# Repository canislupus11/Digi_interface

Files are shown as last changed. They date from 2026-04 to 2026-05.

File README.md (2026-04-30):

<div align="center">
<br>


</div>

# Uniwersalny Interfejs Radiowy / Universal Radio Interface

> Kraków, 31 sierpnia 2026 | Hackerspace Kraków  
> Licencja / License: [CC BY-NC-SA](https://creativecommons.org/licenses/by-nc-sa/4.0/)

---

##  Polski (English below)

### Opis projektu

Uniwersalny interfejs radiowy to otwarto-sprzętowy projekt płytki PCB, której celem jest stworzenie jak najbardziej elastycznego interfejsu do **emisji cyfrowych** oraz **zdalnej kontroli urządzeń radiowych (TRX)**. Interfejs zaprojektowano z myślą o kompatybilności z możliwie największą liczbą modeli i producentów transceiverów.

### Główne założenia

- **Uniwersalność** – współpraca z szeroką gamą modeli TRX różnych producentów
- **Minimalizacja okablowania** – w skrajnym przypadku wystarczy kabel USB i kabel sygnałowy do radia
- **Pełna separacja galwaniczna** – izolacja zaraz za gniazdem USB chroni sprzęt przed przepięciami i biegającym RF

### Moduły

| # | Moduł | Chip |
|---|---|---|
| 1 | HUB USB | **Fe1.1s** |
| 2 | Kodek dźwięku na USB (źródło dla emisji cyfrowych) | **CM108B** |
| 3 | 4-portowy konwerter USB → UART (CAT/CI-V, CW, PTT, FSK) | **CP2105** |
| 4 | Konwerter poziomów RS232/TTL | **MAX232** |
| 5 | Zasilacz (szeroki zakres napięć wejściowych: 7–18 V) | **AMS1117-5.0** |
| 6 | Moduł zworkologii – konfiguracja portów CAT, linii CW, PTT i FSK (w tym z konwerterem poziomów) | – |

### PCB

- Dwustronna płytka w technologii SMD
- Projekt wykonany w **KiCad 9** — pliki schematu, PCB oraz biblioteki footprintów i symboli dostępne w tym repozytorium
- Elementy mają przypisane identyfikatory JLCPCB, dzięki czemu można bezpośrednio zamówić płytkę z usługą montażu SMD (PCBA) — wystarczy wygenerować pliki Gerber, BOM i pliki pick & place z KiCad i wgrać je na stronę JLCPCB
- Katalog `bom/` zawiera interaktywny plik HTNL ułatwiający montaż

### Jak zacząć

1. Sklonuj lub pobierz repozytorium
2. Otwórz `interfejs_digi.kicad_pro` w KiCad 9
3. Przejrzyj schemat (`interfejs_digi.kicad_sch`) i projekt PCB (`interfejs_digi.kicad_pcb`)
4. Wygeneruj pliki Gerber, BOM oraz pick & place z poziomu KiCad
5. Wgraj pliki na stronę [JLCPCB](https://jlcpcb.com) i zamów płytkę z montażem SMD (PCBA) — identyfikatory elementów są już uzupełnione
6. Po otrzymaniu płytki skonfiguruj zworki zgodnie z używanym modelem TRX

### Pinout gniazd RJ45

Interfejs wyprowadza sygnały na dwóch gniazdach RJ45 (HX-RJ45 90 5631-1X1 8P8C).

**RJ1 — gniazdo główne**

| Pin | Sygnał | Opis |
|-----|---|---|
| 1 | CAT1\_RX | CAT RX/CI-V (port 1) |
| 2 | CAT1\_TX | CAT TX (port 1) |
| 3 | GND\_IN | Masa zasilania |
| 4 | PWR\_IN | Zasilanie 7-18V (wejście) |
| 5 | PTT\_OUT | Wyjście PTT (otwarty dren, tranzystor 2N7002) |
| 6 | GND | Masa sygnałowa |
| 7 | AUDIO\_OUT | Wyjście audio do radia (TX) |
| 8 | AUDIO\_IN | Wejście audio z radia (RX) |

**RJ2 — gniazdo dodatkowe**

| Pin | Sygnał | Opis |
|-----|---|---|
| 1 | CAT2\_RX | CAT RX (port 2) |
| 2 | CAT2\_TX | CAT TX (port 2) |
| 3 | FSK\_OUT | Wyjście FSK (otwarty dren, tranzystor 2N7002) |
| 4 | 5V_OUT | Wyjście 5V za stabilizatorem |
| 5 | CW\_OUT | Wyjście kluczowania CW (otwarty dren, tranzystor 2N7002) |
| 6 | – | Niepodłączony |
| 7 | – | Niepodłączony |
| 8 | – | Niepodłączony |

Wyjścia PTT, CW i FSK są wyjściami otwartego drenu przez tranzystor MOSFET 2N7002 z diodą LED sygnalizacyjną. Masa obu gniazd jest wspólna (pin 10 złącza RJ45 podłączony do GND).

### Konfiguracja zworkami

Zworki J7–J11 pozwalają elastycznie przypisać sygnały do linii sterujących oraz wybrać poziomy napięć. Każda zworka ma 6 pinów (3 pary), co umożliwia niezależny wybór dla każdej linii.

**J7, J8 — CAT\_1 i CAT\_2**

Pod każdym złączem CAT znajduje się goldpin 2×3 z dwiema klasycznymi zworkami — osobno dla linii RX i TX. Obie zworki ustawia się zawsze w tej samej pozycji. Konfiguracja jest wspólna dla CAT\_1 i CAT\_2:

| Pozycja zworek | Poziom sygnału |
|---|---|
| obie zworki **w górze** | TTL (5 V) |
| obie zworki **w dole** | RS232 (±12 V) |

**J9 — CW** — wybór źródła sygnału CW spośród linii UART:

| Pozycja zworki | Źródło |
|---|---|
| piny 1–2 | DTR\_1 |
| piny 3–4 | RTS\_1 |
| piny 5–6 | RTS\_2 |

**J10 — PTT** — wybór źródła sygnału PTT:

| Pozycja zworki | Źródło |
|---|---|
| piny 1–2 | DTR\_1 |
| piny 3–4 | RTS\_1 |
| piny 5–6 | RTS\_2 |

**J11 — FSK** — wybór źródła sygnału FSK:

| Pozycja zworki | Źródło |
|---|---|
| piny 1–2 | DTR\_2 |
| piny 3–4 | RTS\_2 |
| piny 5–6 | RTS\_1 |

**J2 — CI-V** — gniazdo CI-V (Icom). Po włożeniu zworki sygnał CAT1\_TX\_TTL jest zwrotnie podłączony przez diodę D5 (1N5819WS) do CAT1\_RX\_TTL, realizując magistralę jednolinową wymaganą przez protokół CI-V.

**LDO\_BYPASS** — lutowana zworka (solder jumper) bypasująca stabilizator napięcia (AMS1117-5.0). Jeśli układ jest zasilany napięciem **5 V** zamiast standardowych 7–18 V (np. bezpośrednio z zasilacza 5 V przez gniazdo RJ1 pin 4), należy zewrzeć tę zworkę cyną, aby ominąć regulator LDO.

> **Ostrzeżenie:** Po zwarciu zworki LDO\_BYPASS stabilizator napięcia jest całkowicie pomijany. Napięcie zasilające trafia bezpośrednio na układ bez żadnej regulacji. Podanie napięcia wyższego niż 5 V przy zwartej zworce **może trwale uszkodzić układ**. Przed podaniem zasilania upewnij się, że źródło napięcia dostarcza dokładnie 5 V.

### Licencja

Projekt udostępniony na licencji **Creative Commons BY-NC-SA**. Możesz go swobodnie używać, modyfikować i udostępniać pod warunkiem podania autora, zachowania tej samej licencji i braku użytku komercyjnego.

---

##  English

### Project Description

The Universal Radio Interface is an open-hardware PCB project designed to provide a flexible interface for **digital mode operations** and **remote control of radio transceivers (TRX)**. The board is designed to be compatible with as many TRX models and manufacturers as possible.

### Design Goals

- **Universality** – works with a wide range of TRX models from various manufacturers
- **Minimal cabling** – in the simplest setup only a USB cable and radio signal cable needed
- **Full galvanic isolation** – isolation placed immediately after the USB connector protects equipment from voltage spikes and stray RF

### Modules

| # | Module | Chip |
|---|---|---|
| 1 | USB Hub | **Fe1.1s** |
| 2 | USB Audio Codec (source for digital modes) | **CM108B** |
| 3 | 4-port USB → UART converter (CAT/CI-V, CW, PTT, FSK) | **CP2105** |
| 4 | RS232/TTL Level Converter | **MAX232** |
| 5 | Power Supply (wide input voltage range: 7–18 V) | **AMS1117-5.0** |
| 6 | Jumper configuration module – configures CAT ports, CW, PTT and FSK lines (including level converter options) | – |

### PCB

- Double-sided SMD board
- Designed in **KiCad 9** — schematic, PCB layout, footprint and symbol libraries all included in this repository
- All components have JLCPCB part IDs assigned, so the board can be ordered with SMD assembly (PCBA) — simply generate Gerber, BOM and pick & place files from KiCad and upload them to JLCPCB
- The `bom/` directory contains an interactive HTML file to assist with assembly.

### Getting Started

1. Clone or download this repository
2. Open `interfejs_digi.kicad_pro` in KiCad 9
3. Review the schematic (`interfejs_digi.kicad_sch`) and PCB layout (`interfejs_digi.kicad_pcb`)
4. Generate Gerber, BOM and pick & place files from KiCad
5. Upload the files to [JLCPCB](https://jlcpcb.com) and order the board with SMD assembly (PCBA) — component IDs are already filled in
6. Once the board arrives, configure the jumpers for your TRX model

### RJ45 Connector Pinout

The interface exposes signals on two RJ45 connectors (HX-RJ45 90 5631-1X1 8P8C). 

**RJ1 — Main connector**

| Pin | Signal | Description |
|-----|---|---|
| 1 | CAT1\_RX | CAT/CI-V receive (port 1) |
| 2 | CAT1\_TX | CAT/CI-V transmit (port 1) |
| 3 | GND\_IN | Power ground |
| 4 | PWR\_IN | 7-18V power input |
| 5 | PTT\_OUT | PTT output (open drain, 2N7002 MOSFET) |
| 6 | GND | Signal ground |
| 7 | AUDIO\_OUT | Audio output to radio (TX) |
| 8 | AUDIO\_IN | Audio input from radio (RX) |

**RJ2 — Secondary connector**

| Pin | Signal | Description |
|-----|---|---|
| 1 | CAT2\_RX | CAT receive (port 2) |
| 2 | CAT2\_TX | CAT transmit (port 2) |
| 3 | FSK\_OUT | FSK output (open drain, 2N7002 MOSFET) |
| 4 | 5V_OUT | 5V output, after LDO |
| 5 | CW\_OUT | CW keying output (open drain, 2N7002 MOSFET) |
| 6 | – | Not connected |
| 7 | – | Not connected |
| 8 | – | Not connected |

PTT, CW and FSK outputs are open-drain via 2N7002 MOSFET transistors, each with a status LED indicator. The ground of both connectors is shared (RJ45 pin 10 tied to GND).

### Jumper Configuration

Jumpers J7–J11 allow flexible assignment of signals to control lines and voltage level selection. Each jumper has 6 pins (3 pairs), enabling independent selection per line.

**J7, J8 — CAT\_1 and CAT\_2**

Below each CAT connector there is a 2×3 pin header with two standard jumpers — one for RX and one for TX. Both jumpers are always set to the same position. The configuration applies equally to CAT\_1 and CAT\_2:

| Jumper position | Signal level |
|---|---|
| both jumpers **up** | TTL (5 V) |
| both jumpers **down** | RS232 (±12 V) |

**J9 — CW** — selects the UART line used as the CW source:

| Jumper position | Source |
|---|---|
| pins 1–2 | DTR\_1 |
| pins 3–4 | RTS\_1 |
| pins 5–6 | RTS\_2 |

**J10 — PTT** — selects the PTT source:

| Jumper position | Source |
|---|---|
| pins 1–2 | DTR\_1 |
| pins 3–4 | RTS\_1 |
| pins 5–6 | RTS\_2 |

**J11 — FSK** — selects the FSK source:

| Jumper position | Source |
|---|---|
| pins 1–2 | DTR\_2 |
| pins 3–4 | RTS\_2 |
| pins 5–6 | RTS\_1 |

**J2 — CI-V** — CI-V connector (Icom radios). When a jumper is inserted, CAT1\_TX\_TTL is looped back through diode D5 (1N5819WS) to CAT1\_RX\_TTL, implementing the single-wire bus required by the CI-V protocol.

**LDO\_BYPASS** — solder jumper that bypasses the voltage regulator (AMS1117-5.0). If the board is powered at **5 V** instead of the standard 7–18 V range (e.g. directly from a 5 V supply via RJ1 pin 4), bridge this solder jumper to bypass the LDO regulator.

> **Warning:** When the LDO\_BYPASS solder jumper is bridged, the voltage regulator is completely bypassed. The supply voltage is fed directly to the circuitry with no regulation. Applying more than 5 V with this jumper bridged **can permanently damage the board**. Always verify that your power source provides exactly 5 V before powering on.

### License

This project is released under the **Creative Commons BY-NC-SA** license. You are free to use, modify, and share it as long as you credit the author, keep the same license, and do not use it commercially.

---

*Design by Szymon Reiter / Hackerspace Kraków*

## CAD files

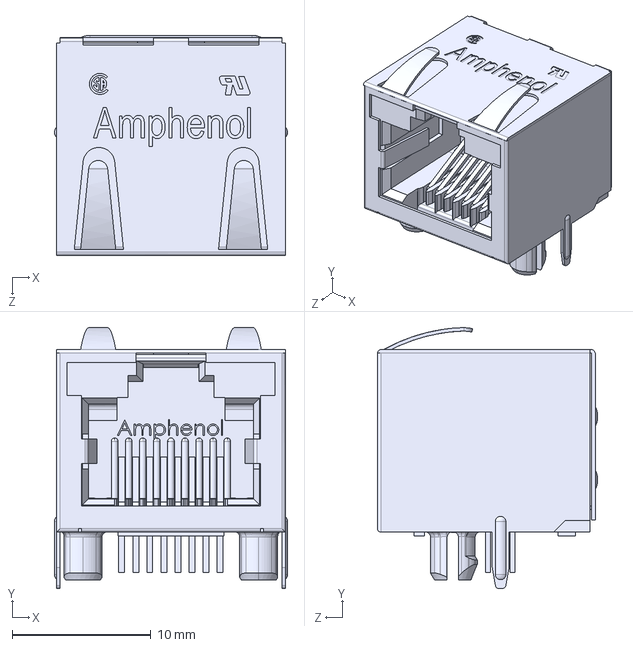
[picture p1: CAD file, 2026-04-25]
KiCad/3dshapes/RJHSE-538B--3DModel-STEP-56544.STEP
16.8 x 18.8 x 15.9 mm

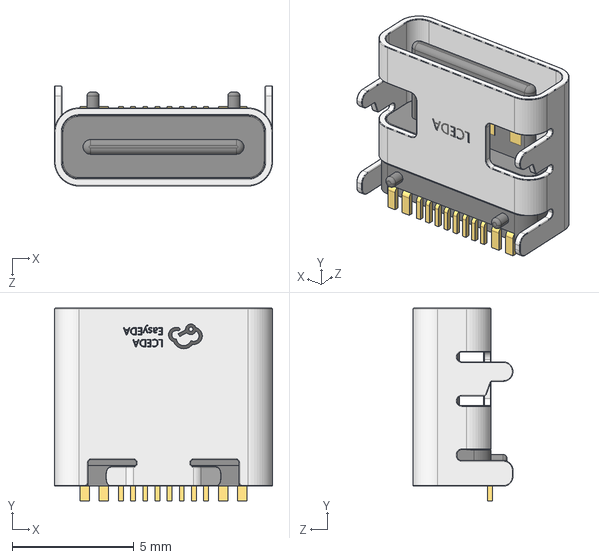
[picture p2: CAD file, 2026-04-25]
KiCad/3dshapes/USB-C-SMD_TYPE-C16PIN.step
8.94 x 7.90 x 4.10 mm

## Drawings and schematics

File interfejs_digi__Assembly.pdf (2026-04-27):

1 | 2 | 3 | 4

A

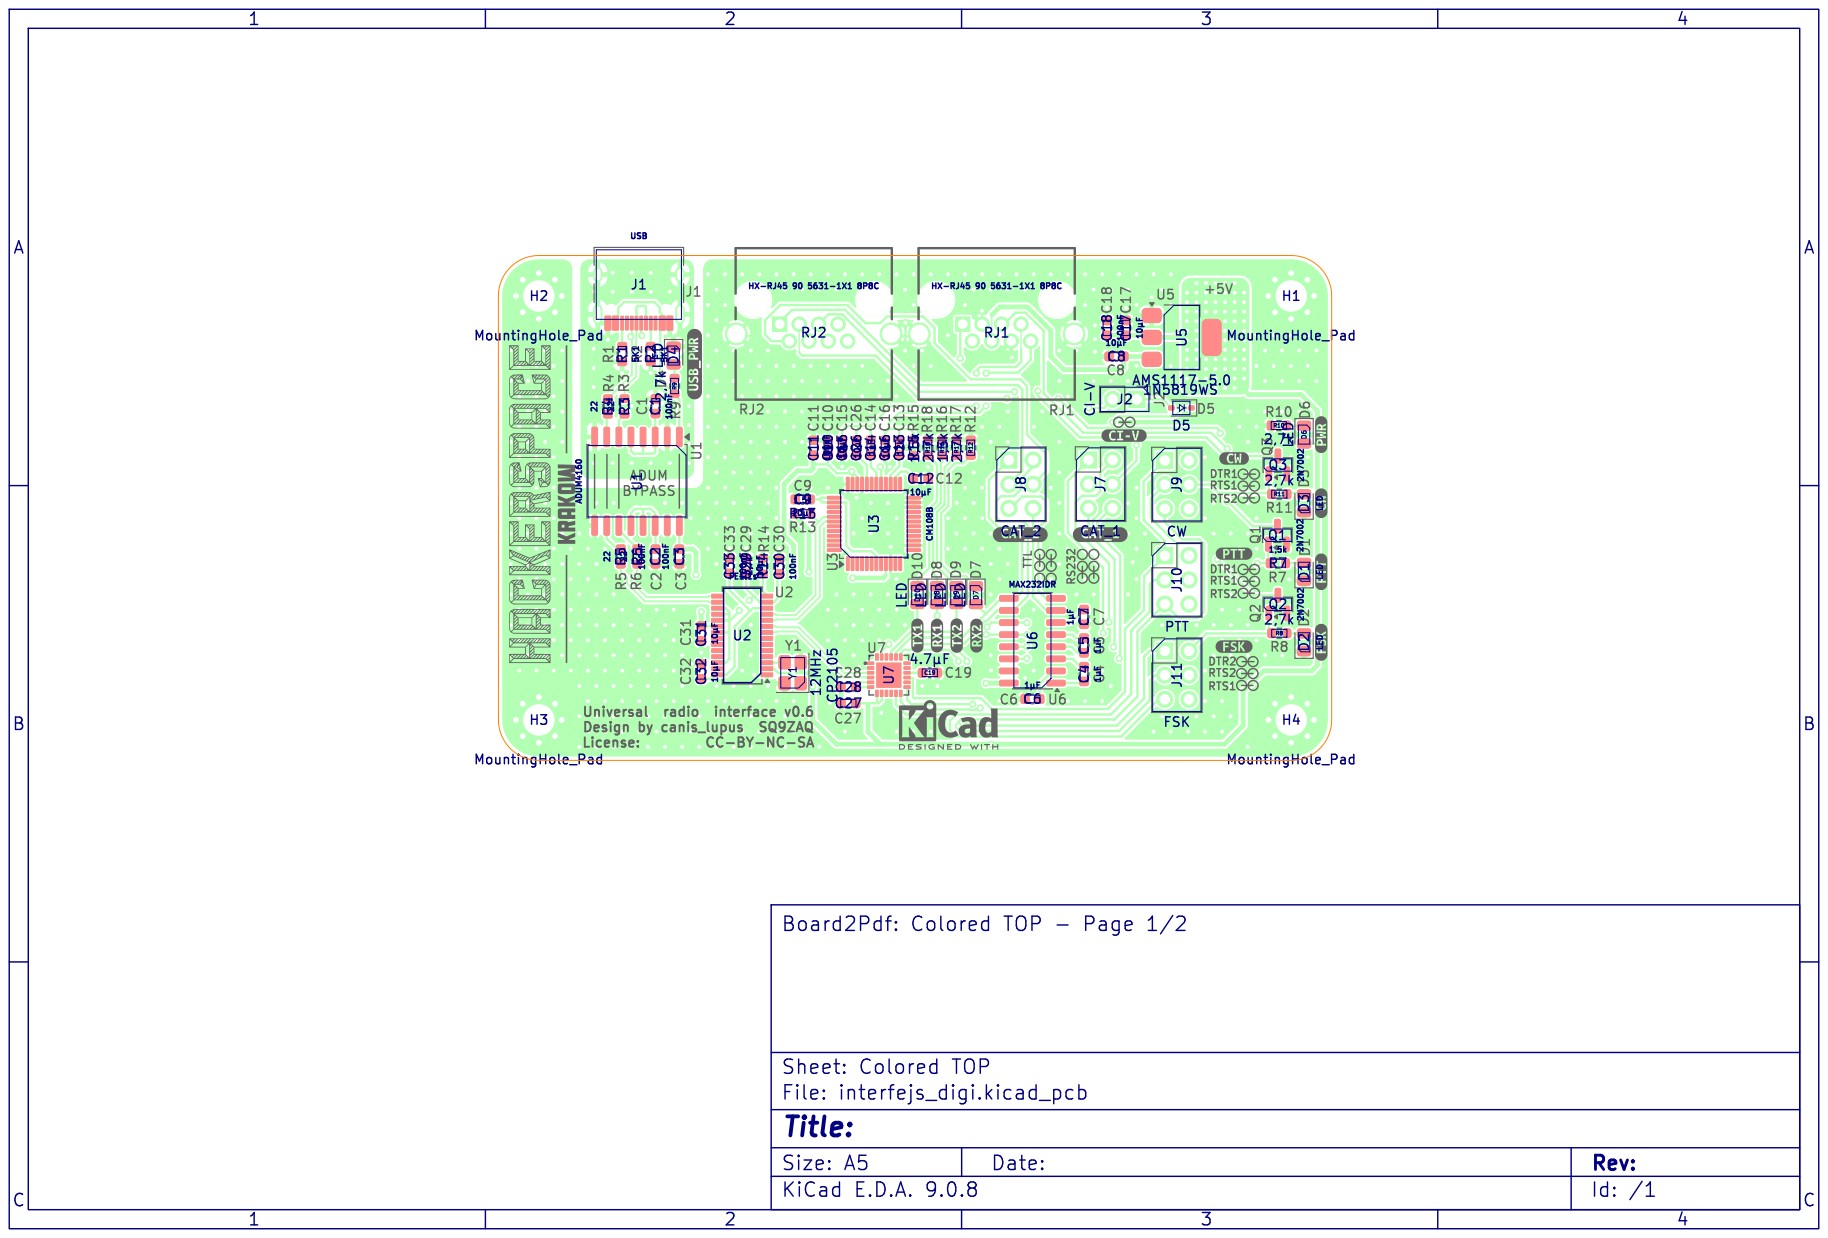
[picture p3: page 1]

Id: /1 Title: File: interfejs_digi.kicad_pcb Sheet: Colored TOP

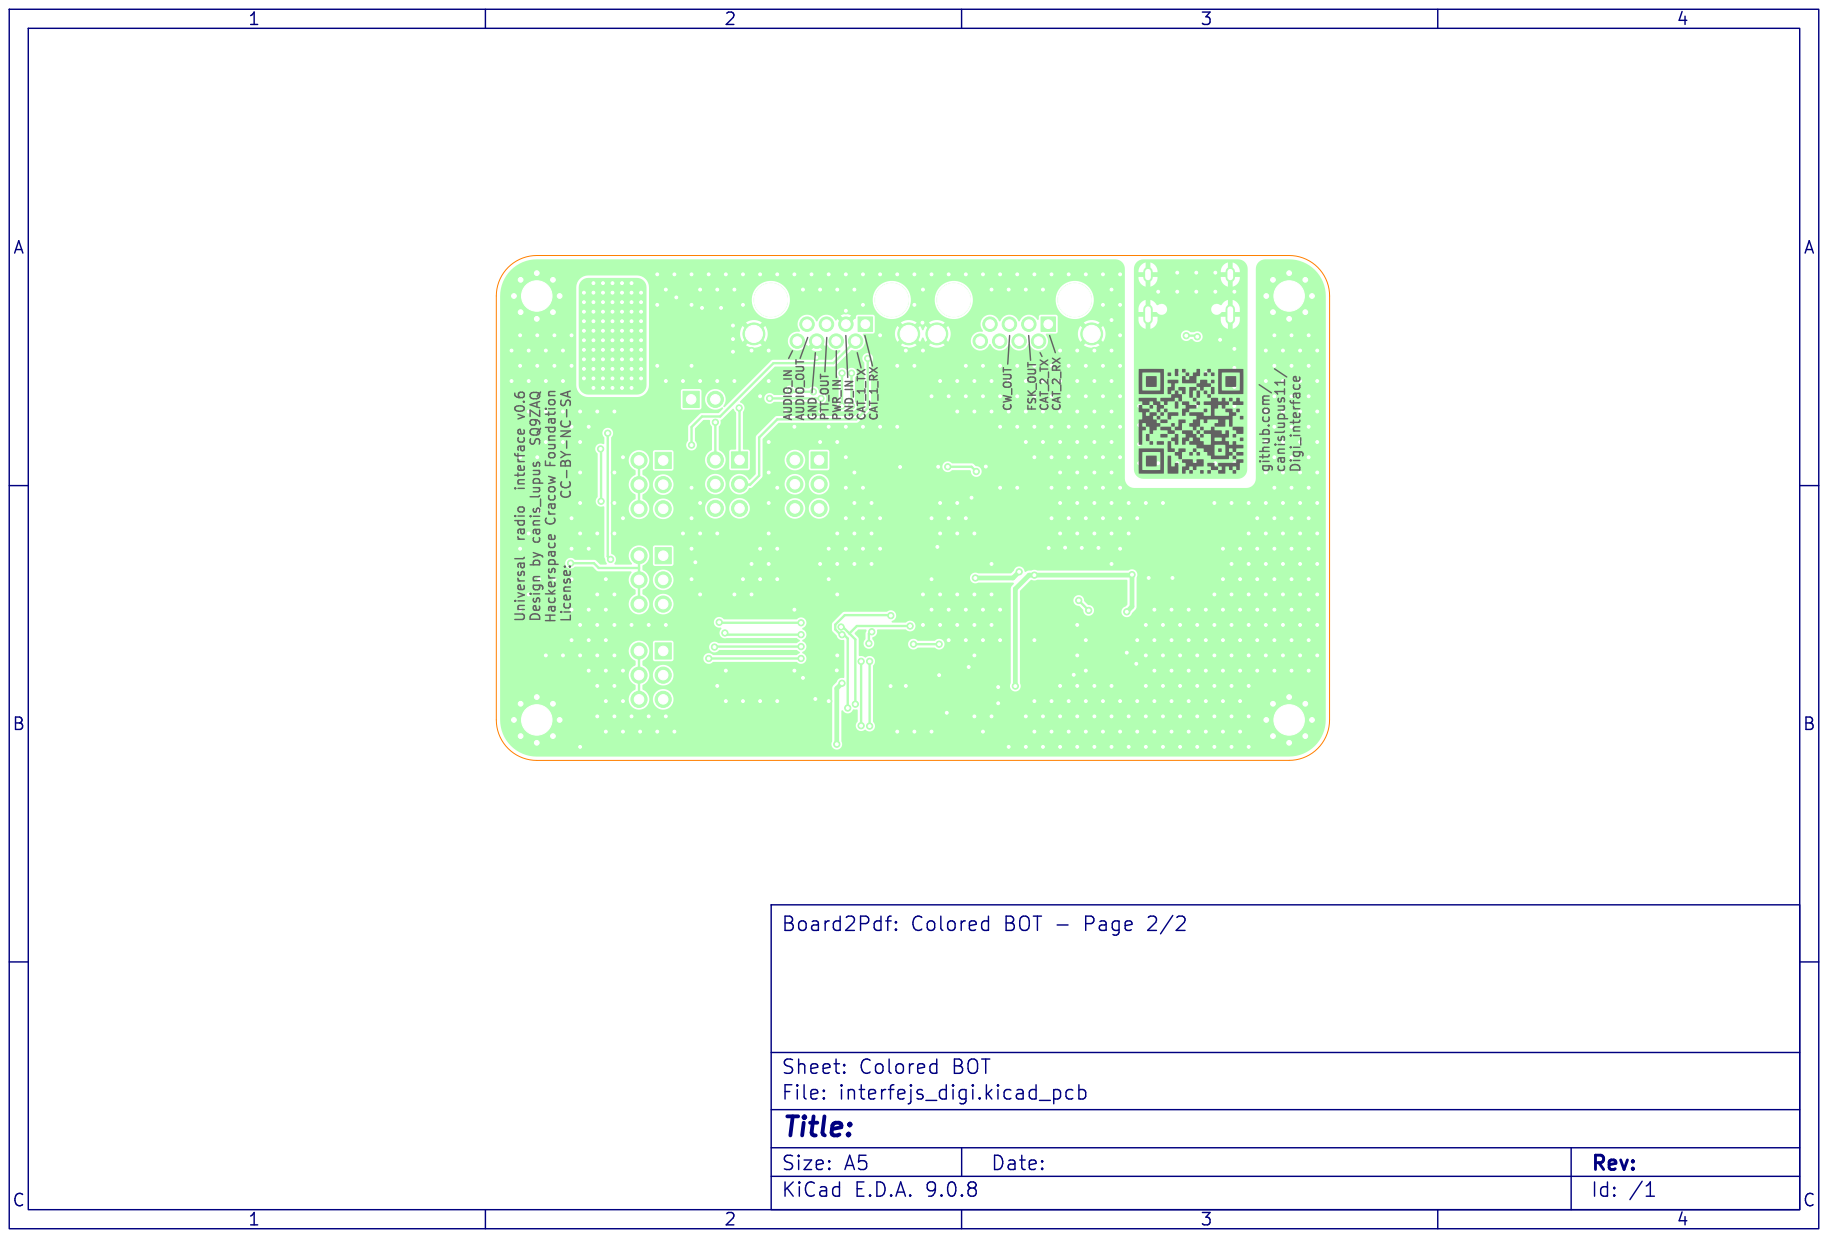
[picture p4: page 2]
Id: /1 Title: File: interfejs_digi.kicad_pcb Sheet: Colored; BOT Board2Pdf:; Colored; BOT -; Page 2/2

CW_OUT FSK_OUT CAT_2_TX CAT_2_RX AUDIO_IN AUDIO_OUT GND PTT_OUT PWR_IN GND_IN CAT_1_TX CAT_1_RX github.com/ canislupus11/ Digi_interface Universal radio interface v0.6 Design by canis_lupus SQ9ZAQ Hackerspace Cracow Foundation License: CC-BY-NC-SA 1 2 3 4 1 2 3 4 ABC ABC Date: KiCad E.D.A. 9.0.8 Size: A5 Rev:

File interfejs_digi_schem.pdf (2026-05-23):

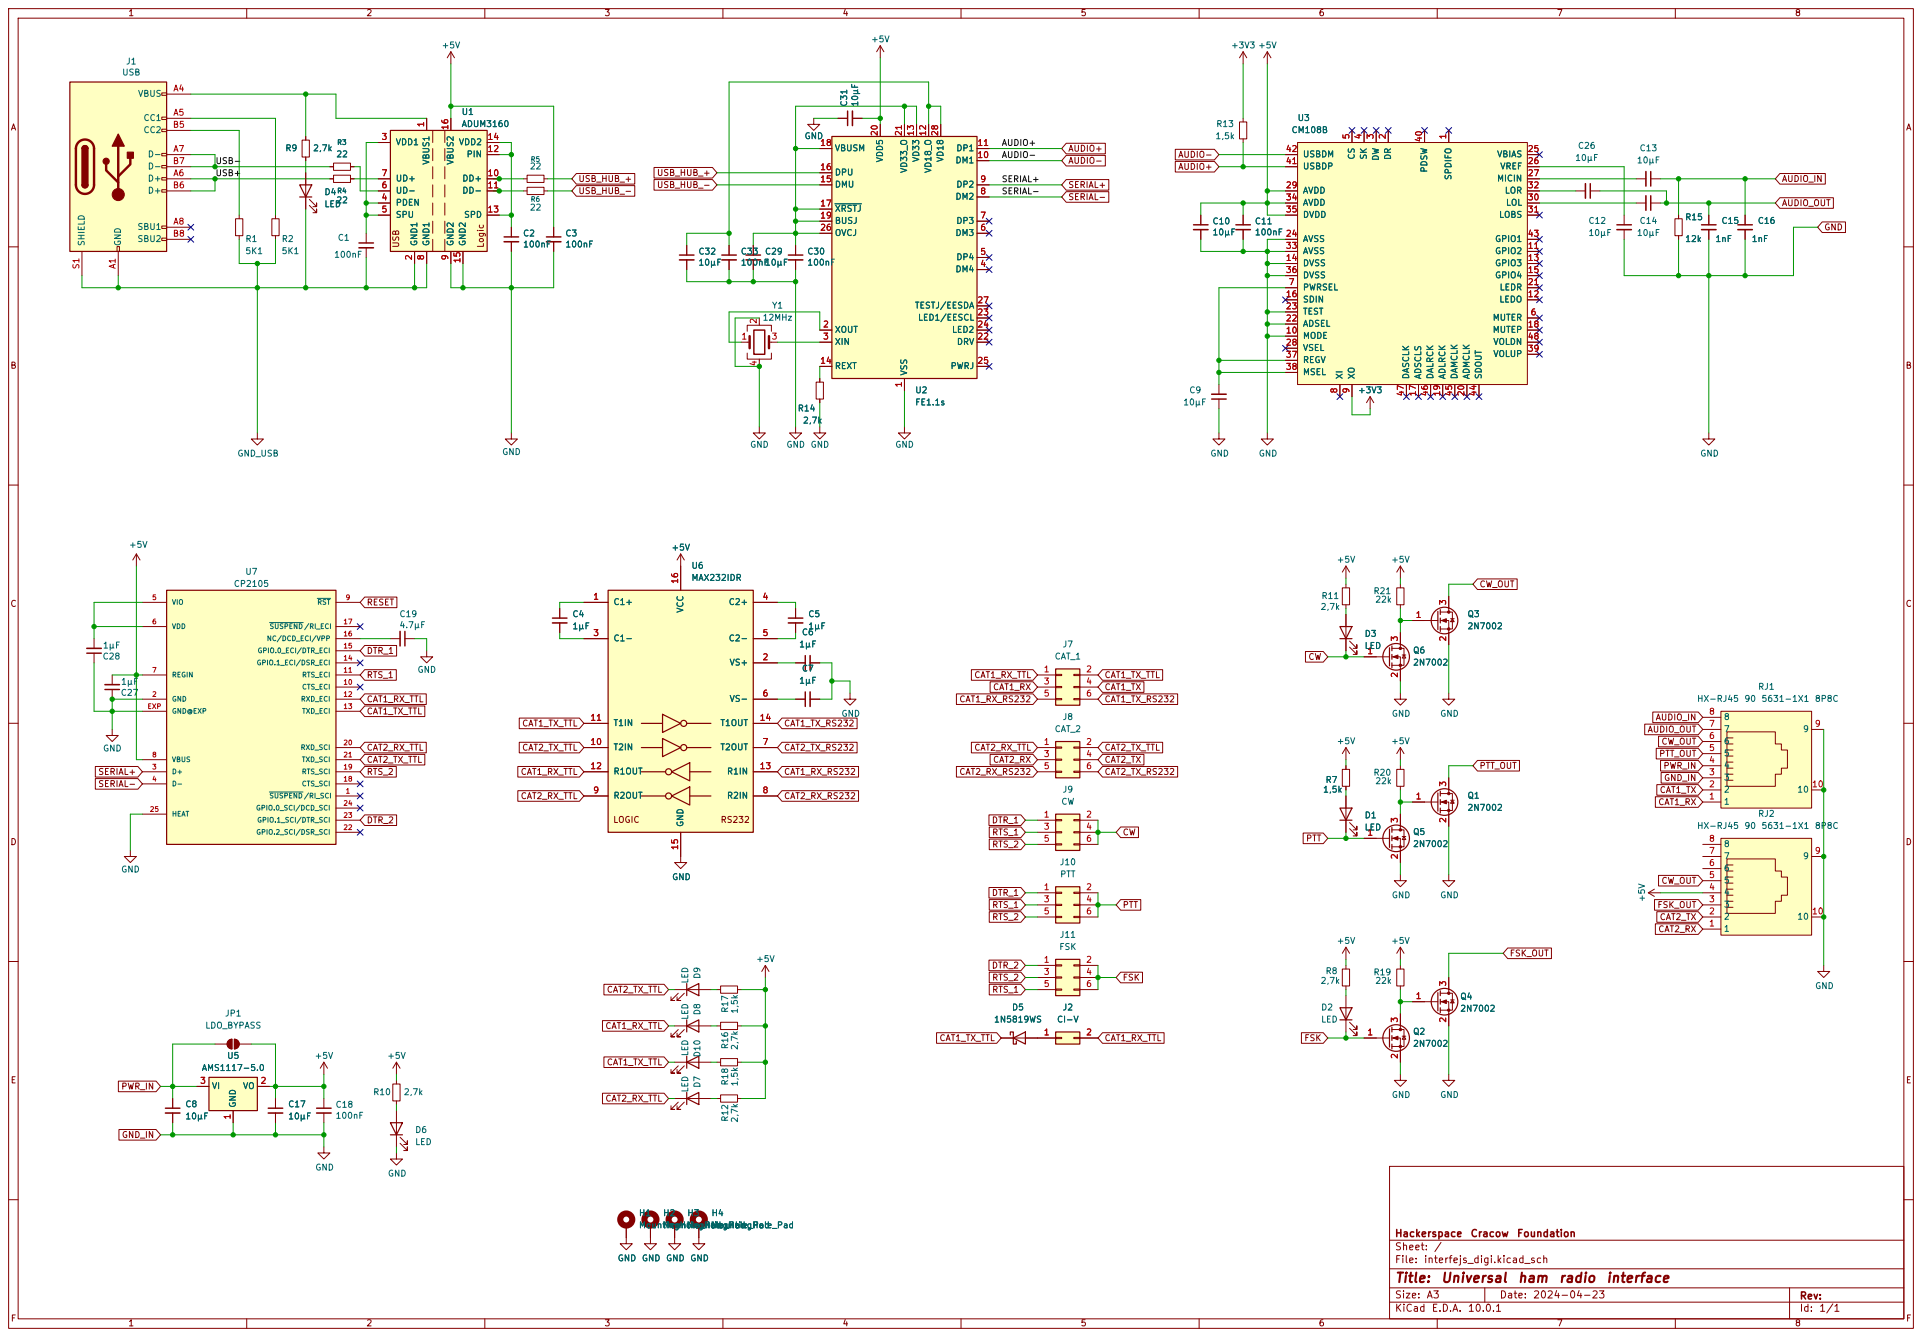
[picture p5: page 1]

5 MUTER 6 PWRSEL 7 XI 8 XO

Hackerspace Cracow Foundation
Sheet: /
File: interfejs_digi.kicad_sch
Title: Universal ham radio interface

Size: A3 | Rev: | F Date: 2024-04-23
KiCad E.D.A. 10.0.1 | Id: 1/1

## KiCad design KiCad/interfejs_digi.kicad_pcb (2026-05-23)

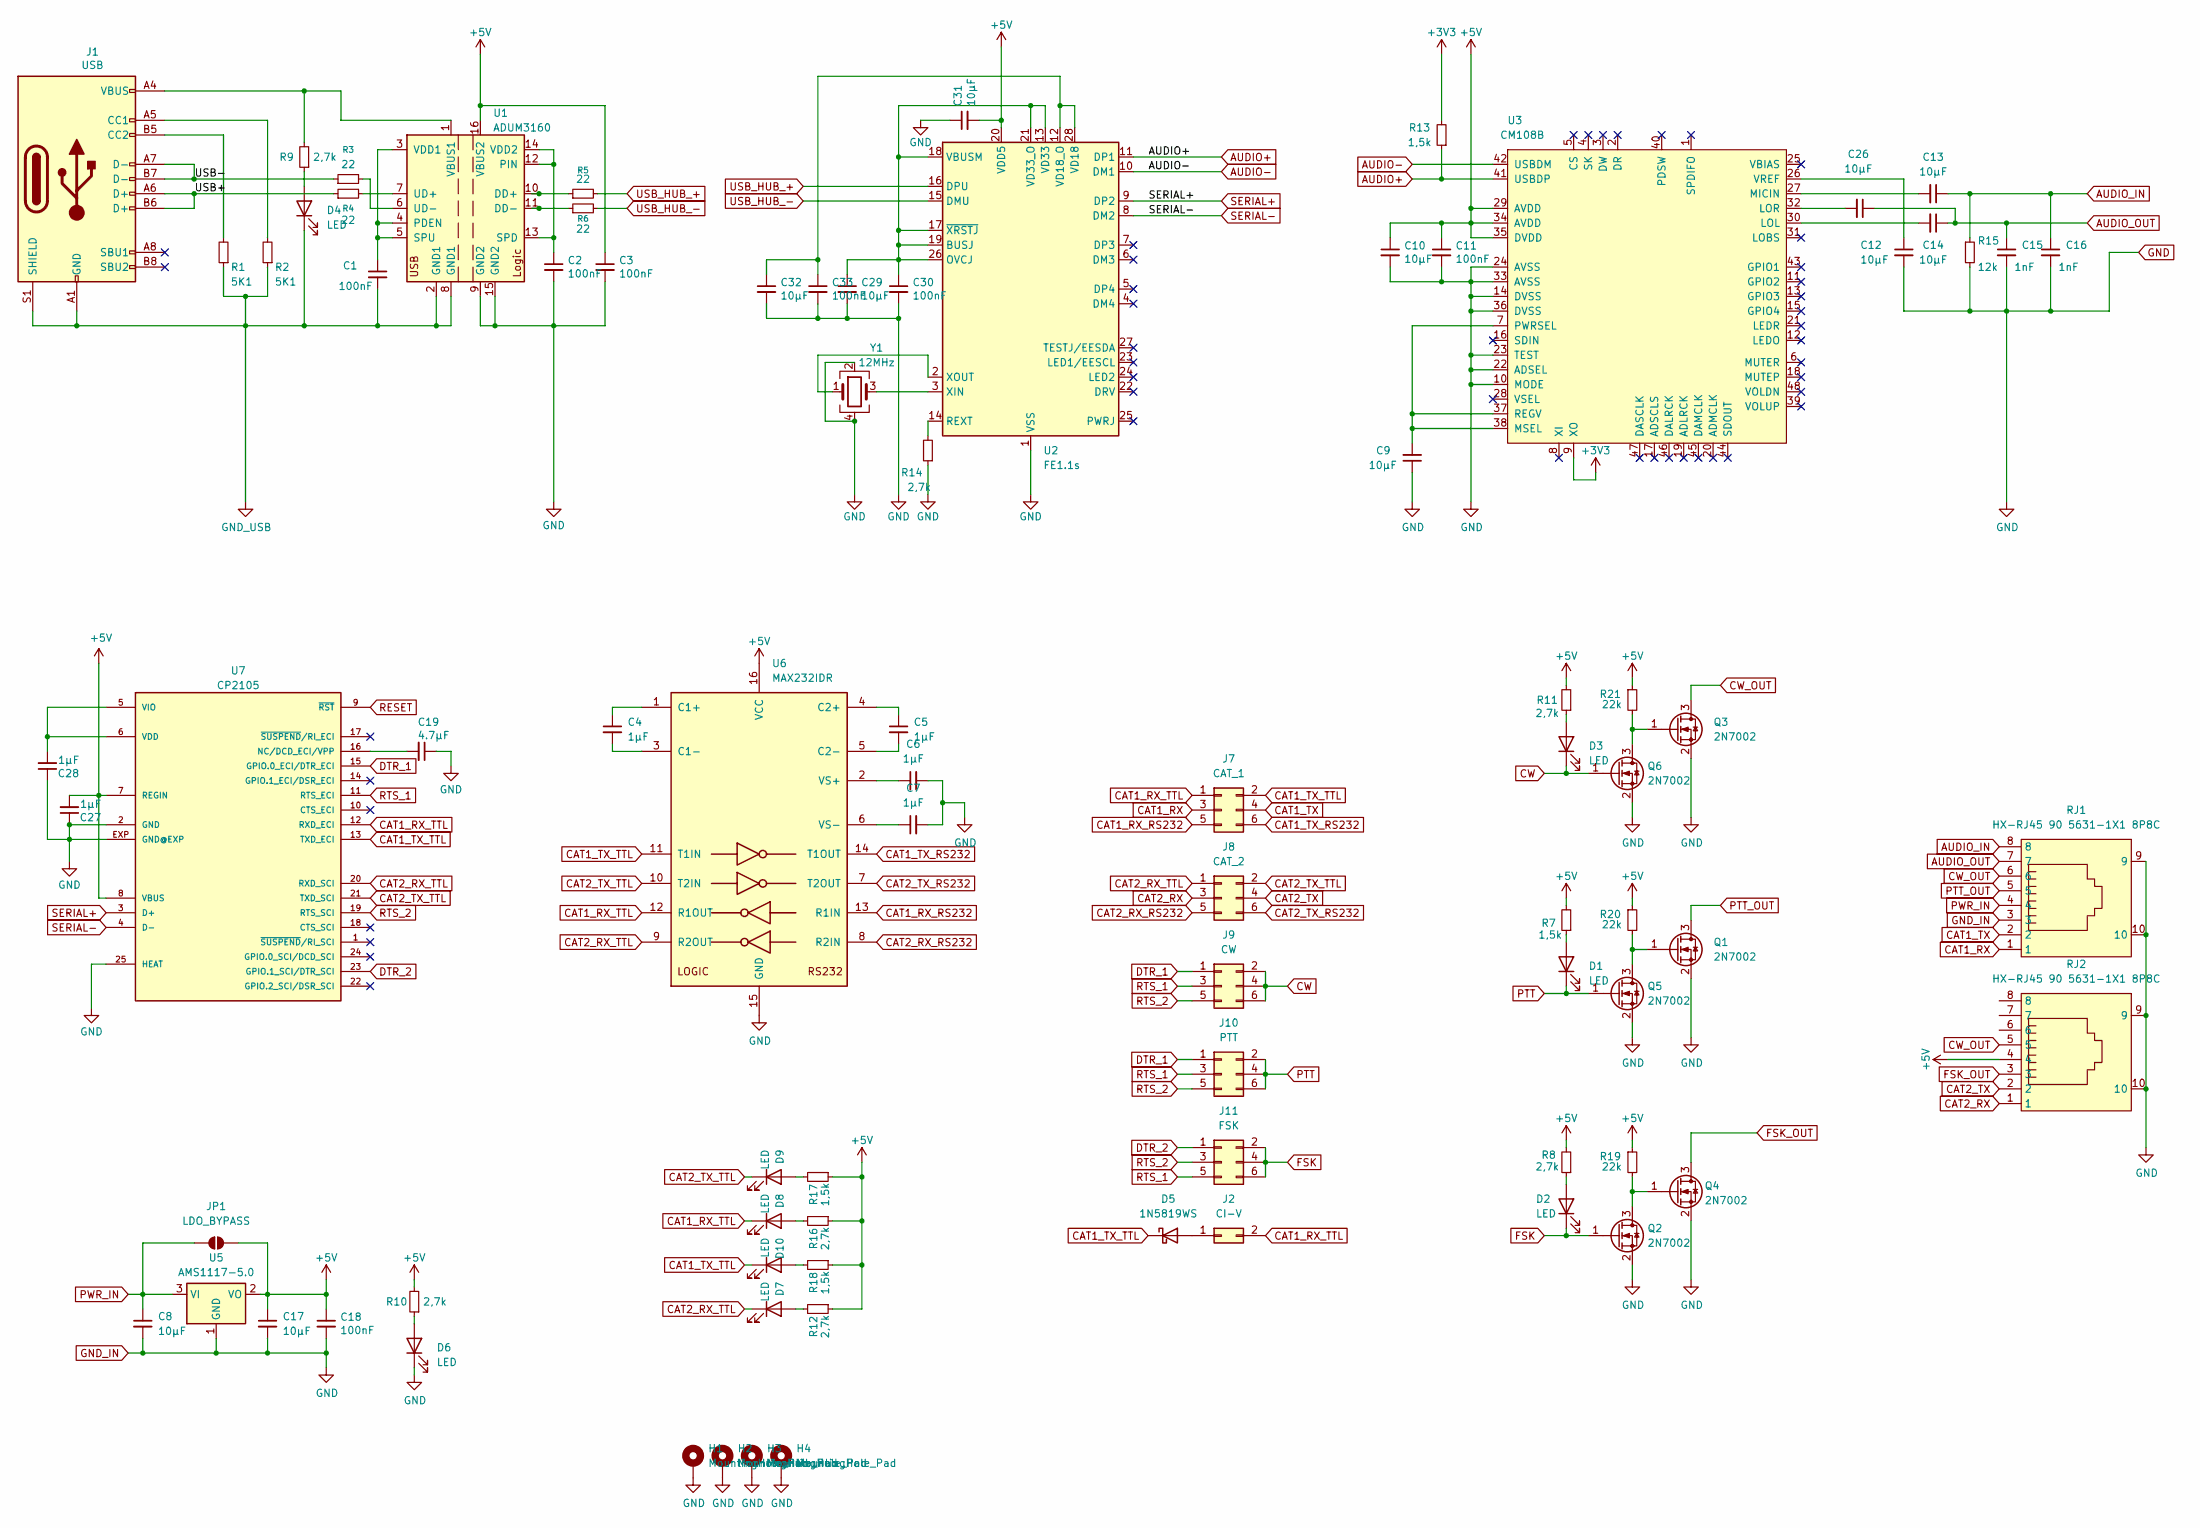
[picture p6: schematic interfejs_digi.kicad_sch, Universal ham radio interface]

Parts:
C1, C2, C3, C11, C18, C30, C33: 100nF; C_0603_1608Metric; LCSC C14663
C4, C5, C6, C7, C27, C28: 1µF; C_0603_1608Metric; LCSC C15849
C8, C9, C10, C12, C13, C14, C17, C26, C29, C31, C32: 10µF; C_0603_1608Metric; LCSC C19702
C15, C16: 1nF; C_0603_1608Metric; LCSC C1588
C19: 4.7µF; C_0603_1608Metric; LCSC C19666
D1, D9, D10: LED; LED_0805_2012Metric; LCSC C84256
D2, D3, D4, D6, D7, D8: LED; LED_0805_2012Metric; LCSC C2297
D5: 1N5819WS; D_SOD-323; LCSC C191023
H1, H2, H3, H4: MountingHole_Pad; MountingHole_3.2mm_M3_Pad_Via
J1: USB; USB_C_Receptacle_HRO_TYPE-C-31-M-12; LCSC C393939
J2: CI-V; PinHeader_1x02_P2.54mm_Vertical; LCSC C41430884
J7: CAT_1; PinHeader_2x03_P2.54mm_Vertical; LCSC C65114
J8: CAT_2; PinHeader_2x03_P2.54mm_Vertical; LCSC C65114
J9: CW; PinHeader_2x03_P2.54mm_Vertical; LCSC C65114
J10: PTT; PinHeader_2x03_P2.54mm_Vertical; LCSC C65114
J11: FSK; PinHeader_2x03_P2.54mm_Vertical; LCSC C65114
JP1: LDO_BYPASS; SolderJumper-2_P1.3mm_Open_RoundedPad1.0x1.5mm
Q1, Q2, Q3, Q4, Q5, Q6: 2N7002; SOT-23; LCSC C8545
R1, R2: 5K1; R_0603_1608Metric; LCSC C23186
R3, R4, R5, R6: 22; R_0603_1608Metric; LCSC C23345
R7, R13, R17, R18: 1,5k; R_0603_1608Metric; LCSC C22843
R8, R9, R10, R11, R12, R14, R16: 2,7k; R_0603_1608Metric; LCSC C13167
R15: 12k; R_0603_1608Metric; LCSC C22790
R19, R20, R21: 22k; R_0603_1608Metric; LCSC C31850
RJ1, RJ2: HX-RJ45 90 5631-1X1 8P8C; RJ456-TH_HX-RJ45-90-5631-1X1-8P8C; LCSC C25168869
U1: ADUM3160; SOIC-16W_7.5x10.3mm_P1.27mm; LCSC C284149
U2: FE1.1s; SSOP-28_3.9x9.9mm_P0.635mm; LCSC C9359
U3: CM108B; LQFP-48_7x7mm_P0.5mm; LCSC C371347
U5: AMS1117-5.0; SOT-223-3_TabPin2; LCSC C6187
U6: MAX232IDR; SOIC-16_3.9x9.9mm_P1.27mm; JLCPCB# C59824
U7: CP2105; QFN-24_L4.0-W4.0-P0.50-BL-EP2.6; LCSC C109102
Y1: 12MHz; Crystal_SMD_3225-4Pin_3.2x2.5mm; LCSC C9002

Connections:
+3V3: R13.2, U3.9 (XO)
+5V: C3.1, C10.1, C11.1, C17.1, C18.1, C27.2, C31.2, JP1.2 (B), R7.2, R8.2, R10.2, R11.2, R12.1, R16.1, R17.1, R18.1, R19.1, R20.1, R21.1, RJ2.4, U1.16 (VBUS2), U2.20 (VDD5), U3.29 (AVDD), U3.34 (AVDD), U3.35 (DVDD), U5.2 (VO), U6.16 (VCC), U7.7 (REGIN), U7.8 (VBUS)
/USB+: J1.A6 (D+), J1.B6 (D+), R4.1
/USB-: J1.A7 (D-), J1.B7 (D-), R3.1
AUDIO+: R13.1, U2.11 (DP1), U3.41 (USBDP)
AUDIO-: U2.10 (DM1), U3.42 (USBDM)
AUDIO_IN: C13.1, C16.1, R15.1, RJ1.8
AUDIO_OUT: C14.1, C15.1, C26.1, RJ1.7
CAT1_RX: J7.3, RJ1.1
CAT1_RX_RS232: J7.5, U6.13 (R1IN)
CAT1_RX_TTL: D8.1 (K), J2.2, J7.1, U6.12 (R1OUT), U7.12 (RXD_ECI)
CAT1_TX: J7.4, RJ1.2
CAT1_TX_RS232: J7.6, U6.14 (T1OUT)
CAT1_TX_TTL: D5.1 (K), D10.1 (K), J7.2, U6.11 (T1IN), U7.13 (TXD_ECI)
CAT2_RX: J8.3, RJ2.1
CAT2_RX_RS232: J8.5, U6.8 (R2IN)
CAT2_RX_TTL: D7.1 (K), J8.1, U6.9 (R2OUT), U7.20 (RXD_SCI)
CAT2_TX: J8.4, RJ2.2
CAT2_TX_RS232: J8.6, U6.7 (T2OUT)
CAT2_TX_TTL: D9.1 (K), J8.2, U6.10 (T2IN), U7.21 (TXD_SCI)
CW: D3.1 (K), J9.2, J9.4, J9.6, Q6.1 (G)
CW_OUT: Q3.3 (D), RJ1.6, RJ2.5
DTR_1: J9.1, J10.1, U7.15 (GPIO.0_ECI/DTR_ECI)
DTR_2: J11.1, U7.23 (GPIO.1_SCI/DTR_SCI)
FSK: D2.1 (K), J11.2, J11.4, J11.6, Q2.1 (G)
FSK_OUT: Q4.3 (D), RJ2.3
GND: C2.2, C3.2, C6.2, C7.2, C8.2, C9.1, C10.2, C11.2, C12.2, C15.2, C16.2, C17.2, C18.2, C19.1, C27.1, C28.1, C29.2, C30.2, C31.1, C32.2, C33.2, D6.1 (K), H1.1, H2.1, H3.1, H4.1, Q1.2 (S), Q2.2 (S), Q3.2 (S), Q4.2 (S), Q5.2 (S), Q6.2 (S), R14.1, R15.2, RJ1.3, RJ1.9, RJ1.10, RJ2.9, RJ2.10, U1.9 (GND2), U1.15 (GND2), U2.1 (VSS), U3.10 (MODE), U3.14 (DVSS), U3.22 (ADSEL), U3.23 (TEST), U3.24 (AVSS), U3.33 (AVSS), U3.36 (DVSS), U5.1 (GND), U6.15 (GND), U7.2 (GND), U7.25 (HEAT), U7.EXP (GND@EXP), Y1.2, Y1.4
GND_USB: C1.2, D4.1 (K), J1.A1 (GND), J1.A12 (GND), J1.B1 (GND), J1.B12 (GND), J1.S1 (SHIELD), R1.1, R2.1, U1.2 (GND1), U1.8 (GND1)
unnamed: D1.2 (A), R7.1
unnamed: D2.2 (A), R8.1
unnamed: D3.2 (A), R11.1
unnamed: D4.2 (A), R9.1
unnamed: D5.2 (A), J2.1
unnamed: D6.2 (A), R10.1
unnamed: D7.2 (A), R12.2
unnamed: D8.2 (A), R16.2
unnamed: D9.2 (A), R17.2
unnamed: D10.2 (A), R18.2
unnamed: J1.A5 (CC1), R2.2
unnamed: J1.B5 (CC2), R1.2
unnamed: Q1.1 (G), Q5.3 (D), R20.2
unnamed: Q2.3 (D), Q4.1 (G), R19.2
unnamed: Q3.1 (G), Q6.3 (D), R21.2
unnamed: R5.1, U1.10 (DD+)
unnamed: R6.1, U1.11 (DD-)
unnamed: C1.1, U1.3 (VDD1), U1.4 (PDEN), U1.5 (SPU)
unnamed: C2.1, U1.12 (PIN), U1.13 (SPD), U1.14 (VDD2)
unnamed: R4.2, U1.7 (UD+)
unnamed: R3.2, U1.6 (UD-)
unnamed: J1.A4 (VBUS), J1.A9 (VBUS), J1.B4 (VBUS), J1.B9 (VBUS), R9.2, U1.1 (VBUS1)
unnamed: C29.1, C30.1, U2.13 (VD33), U2.17 (~XRSTJ), U2.18 (VBUSM), U2.19 (BUSJ), U2.21 (VD33_O), U2.26 (OVCJ)
unnamed: R14.2, U2.14 (REXT)
unnamed: C32.1, C33.1, U2.12 (VD18_O), U2.28 (VD18)
unnamed: U2.3 (XIN), Y1.3
unnamed: U2.2 (XOUT), Y1.1
unnamed: C14.2, U3.30 (LOL)
unnamed: C26.2, U3.32 (LOR)
unnamed: C13.2, U3.27 (MICIN)
unnamed: C9.2, U3.7 (PWRSEL), U3.37 (REGV), U3.38 (MSEL)
unnamed: C12.1, U3.26 (VREF)
unnamed: C4.1, U6.1 (C1+)
unnamed: C4.2, U6.3 (C1-)
unnamed: C5.1, U6.4 (C2+)
unnamed: C5.2, U6.5 (C2-)
unnamed: C6.1, U6.2 (VS+)
unnamed: C7.1, U6.6 (VS-)
unnamed: C19.2, U7.16 (NC/DCD_ECI/VPP)
unnamed: C28.2, U7.5 (VIO), U7.6 (VDD)
PTT: D1.1 (K), J10.2, J10.4, J10.6, Q5.1 (G)
PTT_OUT: Q1.3 (D), RJ1.5
PWR_IN: C8.1, JP1.1 (A), RJ1.4, U5.3 (VI)
RESET: U7.9 (~RST)
RTS_1: J9.3, J10.3, J11.5, U7.11 (RTS_ECI)
RTS_2: J9.5, J10.5, J11.3, U7.19 (RTS_SCI)
SERIAL+: U2.9 (DP2), U7.3 (D+)
SERIAL-: U2.8 (DM2), U7.4 (D-)
USB_HUB_+: R5.2, U2.16 (DPU)
USB_HUB_-: R6.2, U2.15 (DMU)

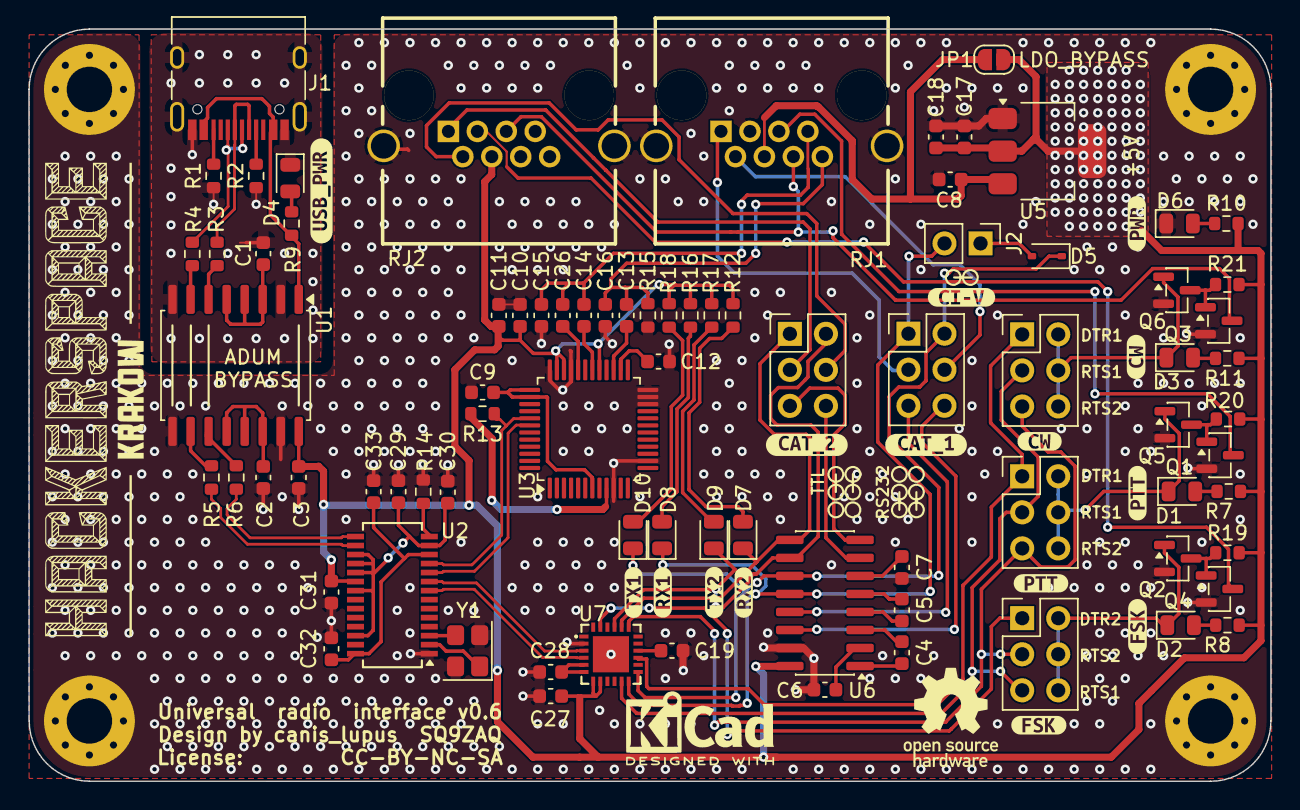
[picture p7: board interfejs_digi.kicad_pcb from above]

Board: 2 copper layers, 87.5 x 53.0 mm, 100 parts (0 on the bottom side), 77 nets.

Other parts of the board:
kibuzzard-69B08B73, kibuzzard-69B08B73#2: G***; kibuzzard-69B08B73
kibuzzard-69B08B92, kibuzzard-69B08B92#2: G***; kibuzzard-69B08B92
kibuzzard-69B08BB3, kibuzzard-69B08BB3#2: G***; kibuzzard-69B08BB3
kibuzzard-69B08C88: G***; kibuzzard-69B08C88
kibuzzard-69B08CED: G***; kibuzzard-69B08CED
kibuzzard-69B08D19: G***; kibuzzard-69B08D19
kibuzzard-69B08EE7: G***; kibuzzard-69B08EE7
kibuzzard-69B0953C: G***; kibuzzard-69B0953C
kibuzzard-69E7E9BF: G***; kibuzzard-69E7E9BF
kibuzzard-69E7EA0C: G***; kibuzzard-69E7EA0C
kibuzzard-69E7EA01: G***; kibuzzard-69E7EA01
kibuzzard-69E7EA14: G***; kibuzzard-69E7EA14

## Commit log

2026-04-25 init commit
    [RJHSE-538B--3DModel-STEP-56544.STEP, USB-C-SMD_TYPE-C16PIN.step, interfejs_bom.csv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]
2026-04-25 ignore production
    [interfejs_bom.csv, interfejs_designators.csv, interfejs_positions.csv]
2026-05-02 zmiana wyjscia starujacego
    [interfejs_digi.kicad_pcb, interfejs_digi.kicad_sch]
